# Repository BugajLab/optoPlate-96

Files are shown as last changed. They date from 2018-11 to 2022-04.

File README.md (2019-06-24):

# optoPlate-96
This repository contains all design files, documentation, and code for you to build and use your own optoPlate-96.
The optoPlates are a series of open-source devices for high-throughput, multi-color optogenetic experiments in microwell plates. Each well of a 96-well plate can be illuminated with up to 3 wavelengths of light, with independent control of illumination timing and intensity for each wavelength. We designed the optoPlates for robust operation in standard cell culture incubators, and for straightforward assembly and use. The optoPlate-96 can be assembled in a few hours with no specialized equipment, at a total cost of ~$600. These devices have enabled us to perform complex, quantitative, and reproducible optogenetic experiments over timescales ranging from minutes to weeks. We hope you will find them equally enabling.

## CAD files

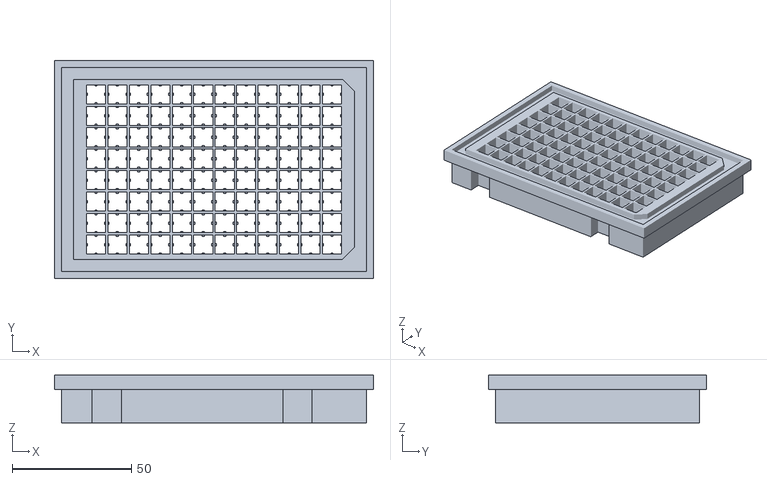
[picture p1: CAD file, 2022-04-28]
1. Assembly_Files/2. 3Dprinting/adapter_96w_384w_TALL.stl
133.8 x 91.5 x 20.0

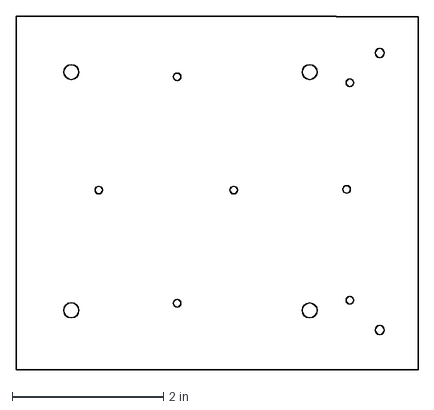
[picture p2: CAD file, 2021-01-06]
1. Assembly_Files/4. WaterjetCutting/aluminumPlateSmall.dxf
5.31 x 4.67 in

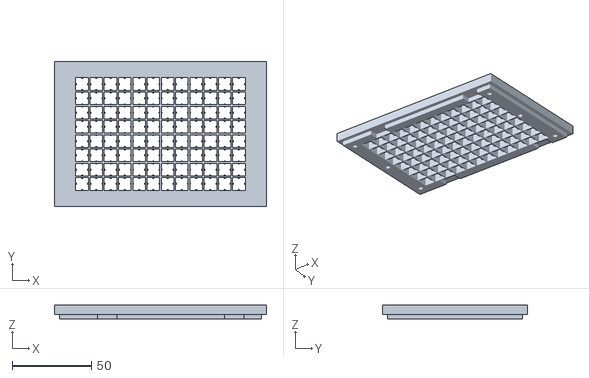
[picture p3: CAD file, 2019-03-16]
1. Assembly_Files/2. 3Dprinting/adapter_96w_384w_SHORT.stl
133.8 x 91.5 x 9.00

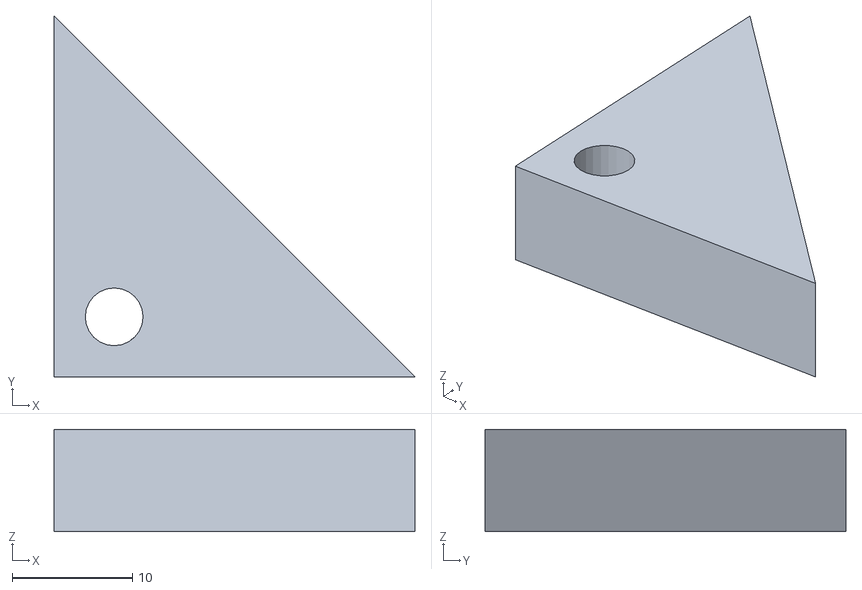
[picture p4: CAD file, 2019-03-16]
1. Assembly_Files/2. 3Dprinting/heatsinkPedestal_v2.stl
30.0 x 30.0 x 8.50

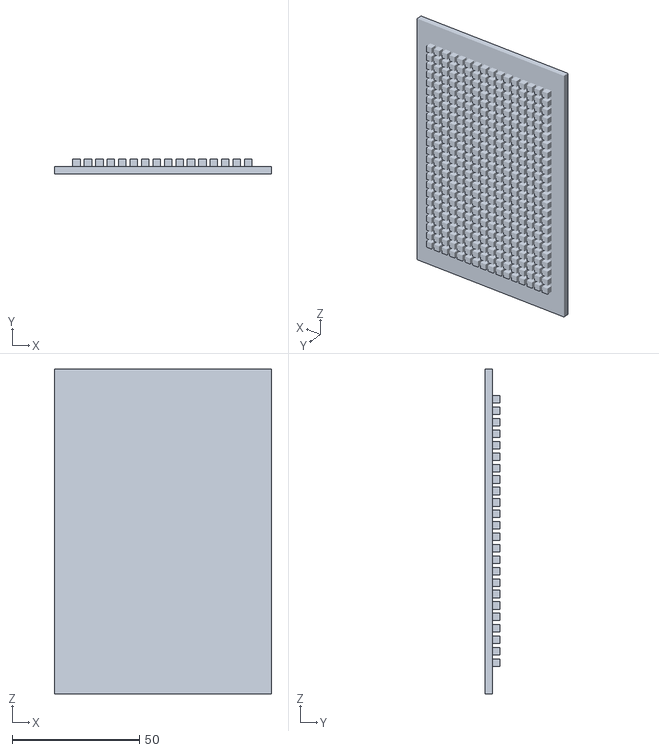
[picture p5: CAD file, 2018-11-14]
1. Assembly_Files/2. 3Dprinting/lid_384w.stl
85.5 x 6.00 x 127.8

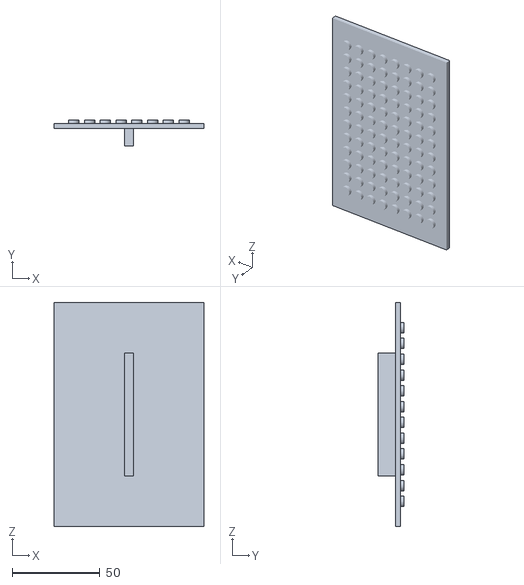
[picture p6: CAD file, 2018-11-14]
1. Assembly_Files/2. 3Dprinting/lid_96w.stl
85.5 x 15.0 x 127.8

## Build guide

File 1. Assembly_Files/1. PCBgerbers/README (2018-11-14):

This folder provides all design files necessary for manufacture of the optoplate illuminator printed circuit board (PCB). 
Included are 11 Gerber files and 1 drill file.
The .zip file contains all necessary Gerber and drill files and can be submitted directly to the PCB manufacturer.

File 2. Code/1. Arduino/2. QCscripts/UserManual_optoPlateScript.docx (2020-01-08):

Lukasz Bugaj

Bugaj Lab

November 18, 2018

User Manual

optoPlate-96_1colorPulse.ino

optoPlate-96_2colorPulse.ino

optoPlate-96_3colorPulse.ino

These scripts control the optoPlate-96, allowing complete control of illumination parameters (timing and intensity) for up to 3 colors for each of 96 positions.

NOTE: Although this manual refers to illumination wavelengths for the 3-color optoPlate configuration (for blue, red, and far-red illumination), the manual applies to all configurations. 1- and 2-color configurations will simply have fewer light intensity variables to specify.

The optoPlate-96_XcolorPulse.ino scripts provide a simple yet powerful framework for dynamic optogenetic perturbations, as described below. However, the optoPlate-96 may be programmed for arbitrarily complex illuminations through customization of the code.

To run this code, the Adafruit_TLC5947 library must be installed. For help installing custom, visit: https://www.arduino.cc/en/Guide/Libraries. Documentation for the Adafruit_TLC5947 library can be found here (https://learn.adafruit.com/tlc5947-tlc59711-pwm-led-driver-breakout/downloads-and-links).

Phases of experiment

The general illumination program consists of 4 programmable phases that allow pulsing cells between 2 experimental illumination conditions (Figure 1A):

0: phaseDelay: the amount of time to delay the start of illumination. This is primarily useful in timecourse experiments when staggered starts are required.

1: phase1: the first illumination condition (can be thought of as the ON phase)

2: phase2: the second illumination condition (or, the OFF phase)

There is also an OFF phase (phaseOFF), in which all LEDs are turned off.

For each phase 0-2, the user can define the duration and intensity of each illumination color. The duration of each phase is specified for each individual LED (phaseTimes). Intensities within each phase can be specified globally for all LEDs or locally for each individual LED.

During an experiment, the LEDs will display the defined illumination conditions sequentially (phaseDelay -> phase1 -> phase2) for the durations specified. Once the end of phase2 has been reached, illumination cycles back to phase1, and the program oscillates between phase1 and phase2 indefinitely following the defined phase timings. If only illumination in phase1 is desired (only ON illumination), then the duration of phase1 should be set arbitrarily large (longer than the desired experiment). Similarly, if the experiment requires that illumination progresses through phase1 and phase2 exactly once, then the duration of phase2 should be defined arbitrarily large.

Pulsing

Within each phase, illumination can be either pulsed or constant (Figure 1B). Pulsed illumination is recommended to minimize both cellular phototoxicity and heat generation from the optoPlate illuminator (heat scales with the amount of power used – or, the total light output). Pulsing parameters—pulse width (pulse) and pulse period (interval)—can be defined for each individual LED. Note that these parameters will dictate pulsing across all phases of illumination (phaseDelay, phase1, phase2) (Figure 1B).

Within phase1, there is also the option to specify illumination during the OFF pulse (the duration between pulsing of phase1-defined illumination settings, Figure 1C). This is mostly useful for three-color optogenetic control of red- and blue-sensitive optogenetic tools (eg, PhyB and iLid), where blue light (ON pulse) must be followed by far-red light (OFF pulse) to prevent blue-light cross-activation of PhyB. The intensity and duration of this OFF pulse are customizable, though the OFF pulse duration should not exceed the amount of time between ON pulses (eg, if the interval is 5s and the ON pulse is 2s, OFF pulse illumination should be < 3s).

Transitions between phases

When the program transitions to phase1 or phase2 and pulsing is used, the ON->OFF or OFF->ON transitions of optogenetic tools can be slower than desired. To speed the activation or inactivation of optogenetic probes, the user can define a length of time (on_millis, off_millis) during which the new illumination setting will constant (not pulsed)(Figure 1D). This results in more step-like (in)activation of the optogenetic probe, and the new state can be further maintained through pulsed illumination. This timing parameter can be defined individually for each position or globally for all wells (on_millisGlobal, off_millisGlobal).

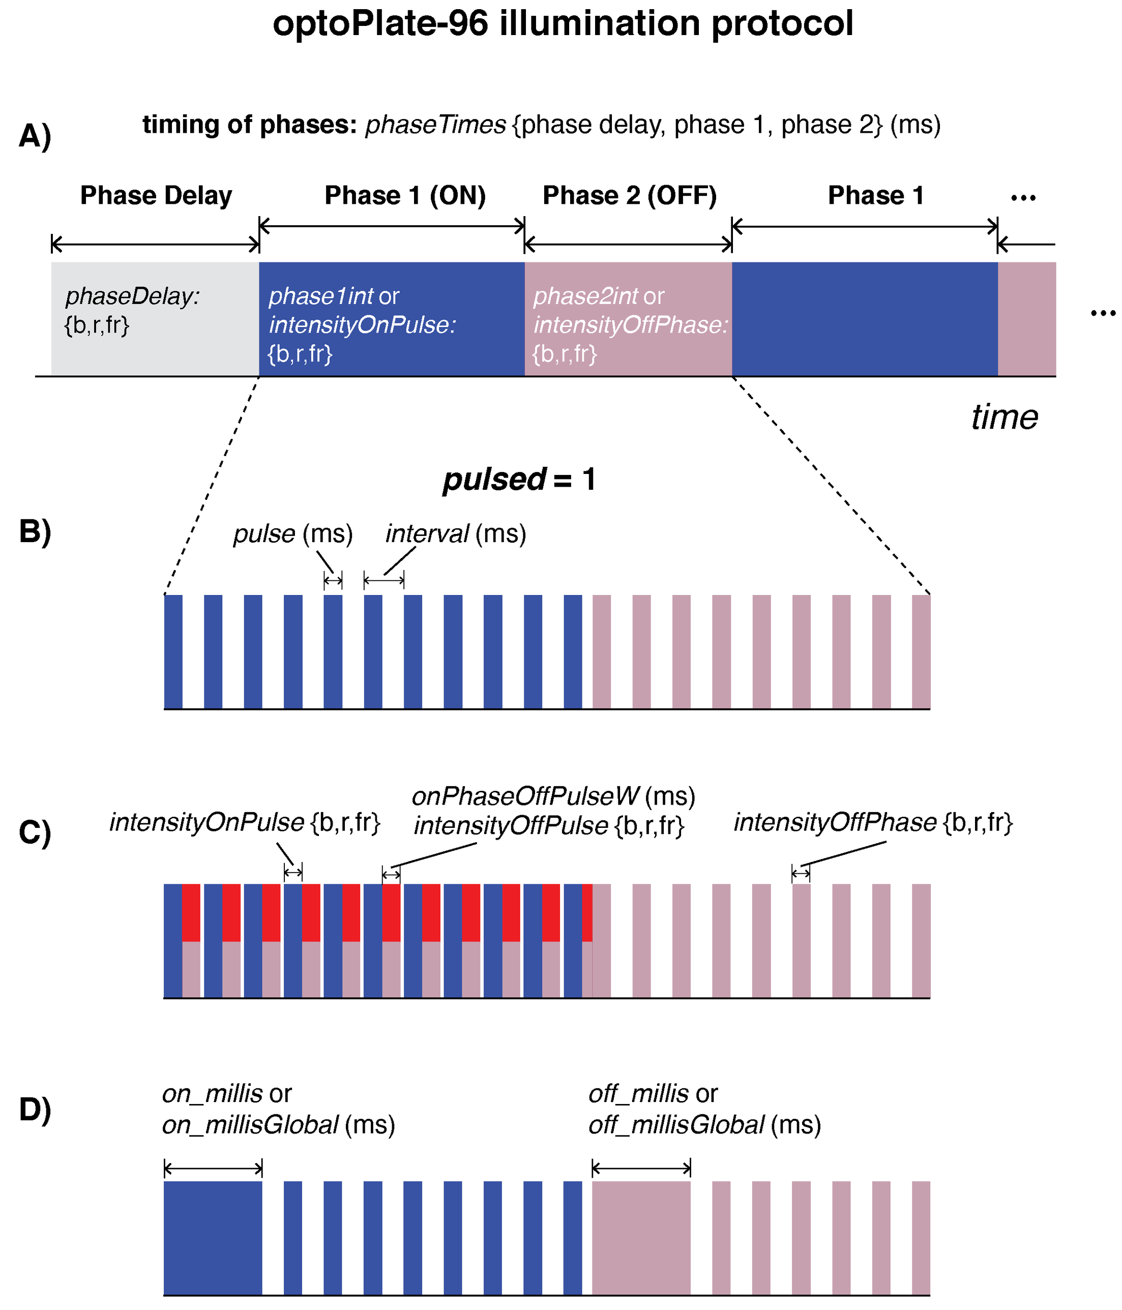
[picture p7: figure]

Figure 1 Visualization of optoPlate-96 illumination protocols and variable definitions. Color of bars indicates colors that would be used in a typical 3-color optogenetic experiment. In the examples provided, phaseDelay could have no illumination, or could illuminate with inactivating far-red light. phase1 would illuminate activating blue or red light, and compensatory far-red light to prevent blue light cross-activation of PhyB. phase2 would illuminate with inactivating far-red light.

A) Schematic of experimental phases. B) If pulsed = 1, pulse and interval define the pulsing parameters. C) Intensity variables are depicted. For 3-color experiments, onPhaseOffPulseW and onPhaseOffPulse allow definition of intensity and timing illumination between activating pulses. D) on_millis and off_millis define the timing of constant illumination at the start of a new illumination phase. This enables more step-like (vs gradual) transitions between phases.

The script is divided into 3 sections:

SECTION 1: This section defines all the variables for each experiment. Variables that need not be changed are labeled *DO NOT CHANGE*. Below are notes on important variables to define:

Time variables: time variables are defined globally, and pointers are used throughout the script to reference these variables. For example, &m30 and &s30 are used to point to the variables that specify 30 minutes and 30 seconds, respectively. Additional time values can be added as new variables in the first section. When adding new variables, make sure to copy the syntax of the other variables. Also, when adding a new time variable, add a corresponding variable in Section 2 in the “test mode” loop. This will ensure that this time variable is properly scaled in test mode.

LEDmode: this defines which of the 96 positions on the LED illuminator are operational. Values are laid out in 96-well format and correspond to LED layout.

Note: arrays of values are most easily defined in a spreadsheet (eg Excel) and then copied and pasted into the Arduino environment

phaseTimes: defines the duration of each phase for each of the 96 LED positions. This variable in particular is most easily defined in a spreadsheet and copied over.

useVarOnPulseIntensity

useVarOffPulseIntensity

useVarOffPhaseIntensity: determine whether LED intensities will be globally defined (0) or variably specified (1) for each individual LED.

intensityOnPulse

intensityOffPulse

intensityOffPhase: define intensities for each color for individual LEDs. First define 96 blue values, then 96 red values, then 96 far-red values.

pulsed: define whether LED illumination will be pulsed (1) or constant (0)

interval, pulse, onPhaseOffPulseW: define pulse periods and pulse widths. Here (and only here), use integer values of milliseconds (do not use pointers to the time variables defined earlier)

varOn, varOff: if constant illumination will be used after transitioning between phases, define whether this will be globally specified (0) or individually for each LED (1).

test: define whether to run the protocol in test mode (test = 1). Test mode allows you to rapidly verify that you have correctly programmed your experiment by speeding up the program by a defined factor. It is strongly recommended to run every protocol in test mode before each experiment to verify correct programming. In test mode, LED illumination is constant (pulsed = 0).

factor: define by what factor to speed up the experiment in test mode.

fanSpeed: define the speed of the fan on the heatsink. The faster the fan, the less sample heating occurs during the experiment. Fan speed can be set from ~100-255. Lower speeds (<100) may result in no fan spinning. Generally, max speed (255) is recommended.

SECTION 2: This is the setup function. This sets the initial settings for the optoPlate run.

SECTION 3: This is the loop function. This code executes the optoPlate experiment as defined by the variables in Section 1.

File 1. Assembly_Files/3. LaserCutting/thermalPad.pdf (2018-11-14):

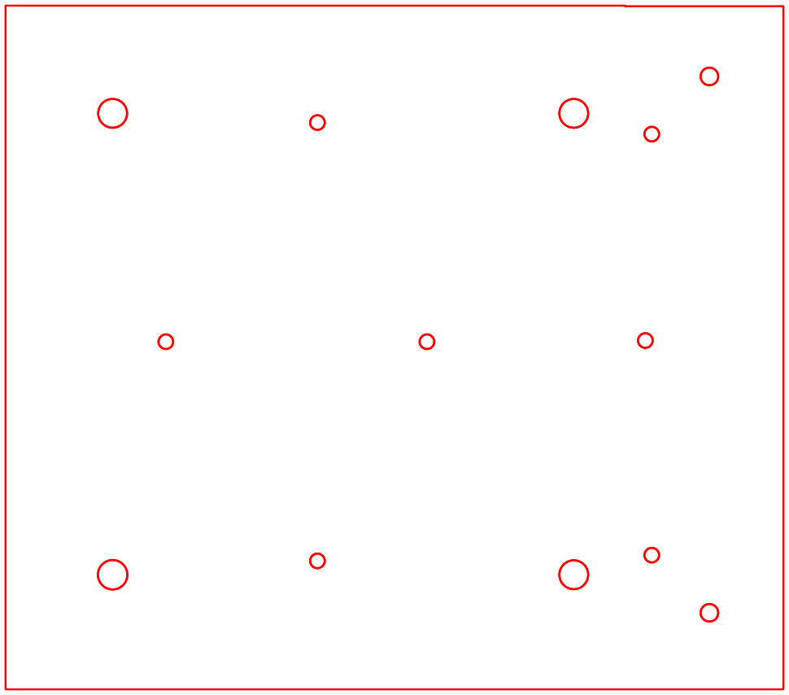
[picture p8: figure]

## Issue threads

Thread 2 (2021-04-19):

Problem with test = 1

mathiaslec, 2021-04-19:
Hi,
Thank you for this amazing tool, we are building an optoplate here!
It looks like there was a error in the code when running it in test mode, some LEDs would not light up.
I fixed it, would you accept a pull request ?
Thank you.

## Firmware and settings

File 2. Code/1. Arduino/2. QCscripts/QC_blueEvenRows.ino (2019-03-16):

#include "Adafruit_TLC5947.h"
#include "Arduino.h"
#include <avr/pgmspace.h>

// How many boards do you have chained?
const uint8_t NUM_TLC5974 = 12;

const uint8_t data  = 4;
const uint8_t clock = 5;
const uint8_t latch = 6;
const uint8_t oe  = 7;  // set to -1 to not use the enable pin (its optional)

//defines numbers of channels total for all colors (288 channels for 3 col 96 well plate)
const int chanNum = 24*NUM_TLC5974;
 
//defines state of pins (0 = OFF)
uint8_t ledState[chanNum/3] = {0};

//Cycle number (for fine pulsing)
uint16_t cycNum[chanNum/3] = {0};
                           
Adafruit_TLC5947 tlc = Adafruit_TLC5947(NUM_TLC5974, clock, data, latch);

// Define whether individual positions will be OFF (0), in timecourse mode (1), or in constant light setting mode (2) (in flash memory, read only)  Rows: A-H. Columns: 1-12                                  
uint8_t const LEDmode[] PROGMEM ={ 
/*
0,  1,  0,  1,  0,  1,  0,  1,  0,  1,  0,  1,
0,  1,  0,  1,  0,  1,  0,  1,  0,  1,  0,  1,
0,  1,  0,  1,  0,  1,  0,  1,  0,  1,  0,  1,
0,  1,  0,  1,  0,  1,  0,  1,  0,  1,  0,  1,
0,  1,  0,  1,  0,  1,  0,  1,  0,  1,  0,  1,
0,  1,  0,  1,  0,  1,  0,  1,  0,  1,  0,  1,
0,  1,  0,  1,  0,  1,  0,  1,  0,  1,  0,  1,
0,  1,  0,  1,  0,  1,  0,  1,  0,  1,  0,  1,
*/

0, 0, 0, 0, 0, 0, 0, 0, 0, 0, 0, 0, 
1, 1, 1, 1, 1, 1, 1, 1, 1, 1, 1, 1,
0, 0, 0, 0, 0, 0, 0, 0, 0, 0, 0, 0, 
1, 1, 1, 1, 1, 1, 1, 1, 1, 1, 1, 1,
0, 0, 0, 0, 0, 0, 0, 0, 0, 0, 0, 0, 
1, 1, 1, 1, 1, 1, 1, 1, 1, 1, 1, 1,
0, 0, 0, 0, 0, 0, 0, 0, 0, 0, 0, 0,
1, 1, 1, 1, 1, 1, 1, 1, 1, 1, 1, 1
};       

                          
const uint8_t OFF = 0;
const uint8_t TIMECOURSE = 1;
const uint8_t CONST_INTENSITY = 2;
const uint8_t OFF_TIMECOURSE = 3;

                                  
//Pulse intervals (flash memory, read only)  Rows: A-H. Columns: 1-12
const uint32_t interval[] PROGMEM = {
2000,	2000,	2000,	2000,	2000,	2000,	2000,	2000,	2000,	2000,	2000,	2000,
2000,	2000,	2000,	2000,	2000,	2000,	2000,	2000,	2000,	2000,	2000,	2000,
2000,	2000,	2000,	2000,	2000,	2000,	2000,	2000,	2000,	2000,	2000,	2000,
2000,	2000,	2000,	2000,	2000,	2000,	2000,	2000,	2000,	2000,	2000,	2000,
2000,	2000,	2000,	2000,	2000,	2000,	2000,	2000,	2000,	2000,	2000,	2000,
2000,	2000,	2000,	2000,	2000,	2000,	2000,	2000,	2000,	2000,	2000,	2000,
2000,	2000,	2000,	2000,	2000,	2000,	2000,	2000,	2000,	2000,	2000,	2000,
2000,	2000,	2000,	2000,	2000,	2000,	2000,	2000,	2000,	2000,	2000,	2000,


};

//Pulse widths (flash memory, read only). Rows: A-H. Columns: 1-12
uint32_t const pulse[] PROGMEM = { 
500,	500,	500,	500,	500,	500,	500,	500,	500,	500,	500,	500,
500,	500,	500,	500,	500,	500,	500,	500,	500,	500,	500,	500,
500,	500,	500,	500,	500,	500,	500,	500,	500,	500,	500,	500,
500,	500,	500,	500,	500,	500,	500,	500,	500,	500,	500,	500,
500,	500,	500,	500,	500,	500,	500,	500,	500,	500,	500,	500,
500,	500,	500,	500,	500,	500,	500,	500,	500,	500,	500,	500,
500,	500,	500,	500,	500,	500,	500,	500,	500,	500,	500,	500,
500,	500,	500,	500,	500,	500,	500,	500,	500,	500,	500,	500,
};
                                  
//LED intensity, for constant intensity setting (flash memory, read only). Rows: A-H. Columns: 1-12
uint16_t const intensity[] PROGMEM = { 
 //BLUE INTENSITIES
100,  100,  100,  100,  100,  100,  100,  100,  100,  100,  100,  100,
100,  100,  100,  100,  100,  100,  100,  100,  100,  100,  100,  100,
100,  100,  100,  100,  100,  100,  100,  100,  100,  100,  100,  100,
100,  100,  100,  100,  100,  100,  100,  100,  100,  100,  100,  100,
100,  100,  100,  100,  100,  100,  100,  100,  100,  100,  100,  100,
100,  100,  100,  100,  100,  100,  100,  100,  100,  100,  100,  100,
100,  100,  100,  100,  100,  100,  100,  100,  100,  100,  100,  100,
100,  100,  100,  100,  100,  100,  100,  100,  100,  100,  100,  100,
 
 //RED INTENTSITIES
100,  100,  100,  100,  100,  100,  100,  100,  100,  100,  100,  100,
100,  100,  100,  100,  100,  100,  100,  100,  100,  100,  100,  100,
100,  100,  100,  100,  100,  100,  100,  100,  100,  100,  100,  100,
100,  100,  100,  100,  100,  100,  100,  100,  100,  100,  100,  100,
100,  100,  100,  100,  100,  100,  100,  100,  100,  100,  100,  100,
100,  100,  100,  100,  100,  100,  100,  100,  100,  100,  100,  100,
100,  100,  100,  100,  100,  100,  100,  100,  100,  100,  100,  100,
100,  100,  100,  100,  100,  100,  100,  100,  100,  100,  100,  100,

//FAR RED INTENSITIES
1000,  1000, 1000, 1000, 1000, 1000, 1000, 1000, 1000, 1000, 1000, 1000,
1000, 1000, 1000, 1000, 1000, 1000, 1000, 1000, 1000, 1000, 1000, 1000,
1000, 1000, 1000, 1000, 1000, 1000, 1000, 1000, 1000, 1000, 1000, 1000,
1000, 1000, 1000, 1000, 1000, 1000, 1000, 1000, 1000, 1000, 1000, 1000,
1000, 1000, 1000, 1000, 1000, 1000, 1000, 1000, 1000, 1000, 1000, 1000,
1000, 1000, 1000, 1000, 1000, 1000, 1000, 1000, 1000, 1000, 1000, 1000,
1000, 1000, 1000, 1000, 1000, 1000, 1000, 1000, 1000, 1000, 1000, 1000,
1000, 1000, 1000, 1000, 1000, 1000, 1000, 1000, 1000, 1000, 1000, 1000,
};
                           
//number of phases in timecourse (including initial delay phase
const uint8_t totPhaseNum = 3;

//Set intensities for various phases.
uint16_t phaseOFF[3] = {0,0,0};
uint16_t phaseDELAY[3] = {0,0,4095};
uint16_t phase1int[3] = {100,0, 0};
uint16_t phase2int[3] = {0,0,4095};

//array of phases
uint16_t *phases[totPhaseNum+1] = {phaseOFF, phaseDELAY, phase1int, phase2int};

//define the current phase (0-3), with 0 being OFF
uint8_t currPhase[chanNum/3] = {0};

//Time variables for pulse lengths
uint32_t s0 = 0;
uint32_t s1 = 1000UL*1UL;
uint32_t s5 = 1000UL*5UL;
uint32_t s10 = 1000UL*10UL;
uint32_t s6 = 1000UL*6UL;
uint32_t s12 = 1000UL*12UL;
uint32_t s18 = 1000UL*18UL;
uint32_t s20 = 1000UL*20UL;
uint32_t s24 = 1000UL*24UL;
uint32_t s30 = 1000UL*30UL;
uint32_t s36 = 1000UL*36UL;
uint32_t s42 = 1000UL*42UL;
uint32_t s45 = 1000UL*45UL;
uint32_t s48 = 1000UL*48UL;
uint32_t s60 = 1000UL*60UL;
uint32_t s120 = 1000UL*120UL;

uint32_t  m3 = 60UL*1000UL*3UL;
uint32_t  m4 = 60UL*1000UL*4UL;
uint32_t  m5 =  60UL*1000UL*5UL;
uint32_t  m8 =  60UL*1000UL*8UL;
uint32_t  m9 =  60UL*1000UL*9UL;
uint32_t  m9_15 =  60UL*1000UL*9.25;
uint32_t  m9_30 =  60UL*1000UL*9.5;
uint32_t  m9_40 =  60UL*1000UL*9.66;
uint32_t  m9_50 =  60UL*1000UL*9.83;
uint32_t  m9_55 =  60UL*1000UL*9.916;
uint32_t  m10 = 60UL*1000UL*10UL;
uint32_t  m15 = 60UL*1000UL*15UL;
uint32_t  m20 = 60UL*1000UL*20UL;
uint32_t  m25 = 60UL*1000UL*25UL;
uint32_t  m30 = 60UL*1000UL*30UL;
uint32_t  m35 = 60UL*1000UL*35UL;
uint32_t  m40 = 60UL*1000UL*40UL;
uint32_t  m45 = 60UL*1000UL*45UL;
uint32_t  m50 = 60UL*1000UL*50UL;
uint32_t  m55 = 60UL*1000UL*55UL;
uint32_t  m60 = 60UL*1000UL*60UL;
uint32_t  m65 = 60UL*1000UL*65UL;
uint32_t  m70 = 60UL*1000UL*70UL;
uint32_t  m75 = 60UL*1000UL*75UL;
uint32_t  m80 = 60UL*1000UL*80UL;
uint32_t  m85 = 60UL*1000UL*85UL;
uint32_t  m88 = 60UL*1000UL*88UL;
uint32_t  m89 = 60UL*1000UL*89UL;
uint32_t  m89_30 = 60UL*1000UL*89.5;
uint32_t m90 = 60UL*1000UL*90UL;
uint32_t m95 = 60UL*1000UL*95UL;
uint32_t m100 = 60UL*1000UL*100UL;
uint32_t m110 = 60UL*1000UL*110UL;
uint32_t m120 = 60UL*1000UL*120UL;
uint32_t m125 = 60UL*1000UL*125UL;
uint32_t m135 = 60UL*1000UL*135UL;

uint32_t h2  = 1000UL*60UL*60UL*2UL;
uint32_t h3  = 1000UL*60UL*60UL*3UL;
uint32_t h4  = 1000UL*60UL*60UL*4UL;
uint32_t h6  = 1000UL*60UL*60UL*6UL;
uint32_t h7  = 1000UL*60UL*60UL*7UL;
uint32_t h7_5  = 1000UL*60UL*60UL*7.5;
uint32_t h8  = 1000UL*60UL*60UL*8UL;
uint32_t h12 = 1000UL*60UL*60UL*12UL;
uint32_t h16 = 1000UL*60UL*60UL*16UL;
uint32_t h18 = 1000UL*60UL*60UL*18UL;
uint32_t h19 = 1000UL*60UL*60UL*19UL;
uint32_t h20 = 1000UL*60UL*60UL*20UL;
uint32_t h22 = 1000UL*60UL*60UL*22UL;
uint32_t h24 = 1000UL*60UL*60UL*24UL;
uint32_t h26 = 1000UL*60UL*60UL*26UL;
uint32_t h30 = 1000UL*60UL*60UL*30UL;
uint32_t h36 = 1000UL*60UL*60UL*36UL;
uint32_t h42 = 1000UL*60UL*60UL*42UL;
uint32_t h48 = 1000UL*60UL*60UL*48UL;

//defines timecourse for each channel as array of pointers
const uint32_t * const phaseTimes[chanNum/3][totPhaseNum] PROGMEM = {
{&s0,&h48,&m10},  {&s0,&h48,&m10},  {&s0,&h48,&m10},  {&s0,&h48,&m10},  {&s0,&h48,&m10},  {&s0,&h48,&m10},  {&s0,&h48,&m10},  {&s0,&h48,&m10},  {&s0,&h48,&m10},  {&s0,&h48,&m10},  {&s0,&h48,&m10},  {&s0,&h48,&m10},
{&s0,&h48,&m10},  {&s0,&h48,&m10},  {&s0,&h48,&m10},  {&s0,&h48,&m10},  {&s0,&h48,&m10},  {&s0,&h48,&m10},  {&s0,&h48,&m10},  {&s0,&h48,&m10},  {&s0,&h48,&m10},  {&s0,&h48,&m10},  {&s0,&h48,&m10},  {&s0,&h48,&m10},
{&s0,&h48,&m10},  {&s0,&h48,&m10},  {&s0,&h48,&m10},  {&s0,&h48,&m10},  {&s0,&h48,&m10},  {&s0,&h48,&m10},  {&s0,&h48,&m10},  {&s0,&h48,&m10},  {&s0,&h48,&m10},  {&s0,&h48,&m10},  {&s0,&h48,&m10},  {&s0,&h48,&m10},
{&s0,&h48,&m10},  {&s0,&h48,&m10},  {&s0,&h48,&m10},  {&s0,&h48,&m10},  {&s0,&h48,&m10},  {&s0,&h48,&m10},  {&s0,&h48,&m10},  {&s0,&h48,&m10},  {&s0,&h48,&m10},  {&s0,&h48,&m10},  {&s0,&h48,&m10},  {&s0,&h48,&m10},
{&s0,&h48,&m10},  {&s0,&h48,&m10},  {&s0,&h48,&m10},  {&s0,&h48,&m10},  {&s0,&h48,&m10},  {&s0,&h48,&m10},  {&s0,&h48,&m10},  {&s0,&h48,&m10},  {&s0,&h48,&m10},  {&s0,&h48,&m10},  {&s0,&h48,&m10},  {&s0,&h48,&m10},
{&s0,&h48,&m10},  {&s0,&h48,&m10},  {&s0,&h48,&m10},  {&s0,&h48,&m10},  {&s0,&h48,&m10},  {&s0,&h48,&m10},  {&s0,&h48,&m10},  {&s0,&h48,&m10},  {&s0,&h48,&m10},  {&s0,&h48,&m10},  {&s0,&h48,&m10},  {&s0,&h48,&m10},
{&s0,&h48,&m10},  {&s0,&h48,&m10},  {&s0,&h48,&m10},  {&s0,&h48,&m10},  {&s0,&h48,&m10},  {&s0,&h48,&m10},  {&s0,&h48,&m10},  {&s0,&h48,&m10},  {&s0,&h48,&m10},  {&s0,&h48,&m10},  {&s0,&h48,&m10},  {&s0,&h48,&m10},
{&s0,&h48,&m10},  {&s0,&h48,&m10},  {&s0,&h48,&m10},  {&s0,&h48,&m10},  {&s0,&h48,&m10},  {&s0,&h48,&m10},  {&s0,&h48,&m10},  {&s0,&h48,&m10},  {&s0,&h48,&m10},  {&s0,&h48,&m10},  {&s0,&h48,&m10},  {&s0,&h48,&m10},
};

//Define constant off times for OFF_TIMECOURSE setting
const uint32_t * const off_millis[] PROGMEM ={
&s0,  &s0,  &s0,  &s0,  &s0,  &s0,  &s0,  &s0,  &s0,  &s0,  &s0,  &s0,
&s0,  &s0,  &s0,  &s0,  &s0,  &s0,  &s0,  &s0,  &s0,  &s0,  &s0,  &s0,
&s0,  &s0,  &s0,  &s0,  &s0,  &s0,  &s0,  &s0,  &s0,  &s0,  &s0,  &s0,
&s0,  &s0,  &s0,  &s0,  &s0,  &s0,  &s0,  &s0,  &s0,  &s0,  &s0,  &s0,
&s0,  &s0,  &s0,  &s0,  &s0,  &s0,  &s0,  &s0,  &s0,  &s0,  &s0,  &s0,
&s0,  &s0,  &s0,  &s0,  &s0,  &s0,  &s0,  &s0,  &s0,  &s0,  &s0,  &s0,
&s0,  &s0,  &s0,  &s0,  &s0,  &s0,  &s0,  &s0,  &s0,  &s0,  &s0,  &s0,
&s0,  &s0,  &s0,  &s0,  &s0,  &s0,  &s0,  &s0,  &s0,  &s0,  &s0,  &s0,
}; //H   
                                  
                                  
//Define constant on times for variable constant Red ON times
const uint32_t * const on_millis[] PROGMEM ={
&s0,	&s0,	&s0,	&s0,	&s0,	&s0,	&s0,	&s0,	&s0,	&s0,	&s0,	&s0,
&s0,	&s0,	&s0,	&s0,	&s0,	&s0,	&s0,	&s0,	&s0,	&s0,	&s0,	&s0,
&s0,  &s0,  &s0,  &s0,  &s0,  &s0,  &s0,  &s0,  &s0,  &s0,  &s0,  &s0,
&s0,  &s0,  &s0,  &s0,  &s0,  &s0,  &s0,  &s0,  &s0,  &s0,  &s0,  &s0,
&s0,  &s0,  &s0,  &s0,  &s0,  &s0,  &s0,  &s0,  &s0,  &s0,  &s0,  &s0,
&s0,  &s0,  &s0,  &s0,  &s0,  &s0,  &s0,  &s0,  &s0,  &s0,  &s0,  &s0,
&s0,  &s0,  &s0,  &s0,  &s0,  &s0,  &s0,  &s0,  &s0,  &s0,  &s0,  &s0,
&s0,  &s0,  &s0,  &s0,  &s0,  &s0,  &s0,  &s0,  &s0,  &s0,  &s0,  &s0,
};  

// define time that IR or Red will be constantly on after ON->OFF transition and OFF->ON transition
uint32_t *IRoffSwitch =  &m5;
uint32_t *REDonSwitch =  &s60;

//define pointers to be used in script for pointing to either a constant switch time or to the variable switch times (on_millis, offmillis)
uint32_t *offTime;
uint32_t *onTime;




//define flag to determine whther a channel has just switched to an OFF(1) or OFF (2) phase. 
uint8_t switchTo[chanNum/3] = { 
  0,0,0,0,0,0,0,0,0,0,0,0,
  0,0,0,0,0,0,0,0,0,0,0,0,
  0,0,0,0,0,0,0,0,0,0,0,0,
  0,0,0,0,0,0,0,0,0,0,0,0,
  0,0,0,0,0,0,0,0,0,0,0,0,
  0,0,0,0,0,0,0,0,0,0,0,0,
  0,0,0,0,0,0,0,0,0,0,0,0,
  0,0,0,0,0,0,0,0,0,0,0,0};
                                  
//define flag to determine if channel just switched to ON phase                                

//define if using phase intensities or variable intensities. 0 to use phase intensities, 1 to use variable.
uint8_t useVarIntensity = 0;

//define if pulsed or constant. 1 for pulsed, 0 for constant
uint8_t pulsed = 0;

//define if in test mode. If in test mode, define "factor" for how much to divide phase times by
uint8_t test = 0;

uint32_t factor = 60UL; //times change from hours to seconds

//keep track of when switched to the current phase
uint32_t lastPhaseSwitch[chanNum/3] = {0};

//use variable times for ON or OFF constant illumination when to red or IR (1 yes, 0 no)?
uint8_t varON = 0;
uint8_t varOFF = 0;

void setup() {
  Serial.begin(9600);
  tlc.begin();
  
  //set initial LED states to 0
  for (int i = 0; i < chanNum/3; i++){
    setAll(i,phaseOFF);
    cycNum[i] = 0;}
    tlc.write();
  
  if (oe >= 0) {
    pinMode(oe, OUTPUT);
    digitalWrite(oe, HIGH);
    }
    
  //if in test mode, divide phase times by defined factor amount to visualize entire timecourse
  if (test){
     s1 = (uint32_t)s1/factor;
     s5 = (uint32_t)s5/factor;
     s10 = (uint32_t)s10/factor;
    s30 = (uint32_t)s30/factor;
    s60 = (uint32_t)s60/factor;
    s120 = (uint32_t)s120/factor;
  
     m3 =  (uint32_t)m3/factor; 
     m4 =  (uint32_t)m4/factor;
     m5 =  (uint32_t)m5/factor;
     m10 = (uint32_t)m10/factor;
     m15 = (uint32_t)m15/factor;
     m20 = (uint32_t)m20/factor;
     m25 = (uint32_t)m25/factor;
     m30 = (uint32_t)m30/factor;
     m35 = (uint32_t)m35/factor;
     m40 = (uint32_t)m40/factor;
     m45 = (uint32_t)m45/factor;
     m50 = (uint32_t)m50/factor;
     m55 = (uint32_t)m55/factor;
     m60 = (uint32_t)m60/factor;
     m65 = (uint32_t)m65/factor;
     m70 = (uint32_t)m70/factor;
     m75 = (uint32_t)m75/factor;
     m80 = (uint32_t)m80/factor;
     m85 = (uint32_t)m85/factor;
     m90 = (uint32_t)m90/factor;
     m95 = (uint32_t)m95/factor;
     m100 = (uint32_t)m100/factor;
     m110 = (uint32_t)m110/factor;
     m120 =(uint32_t)m120/factor;
     m125 =(uint32_t)m125/factor;
     m135 =(uint32_t)m135/factor;
    
    h2 =  (uint32_t)h2/factor;
     h3 =  (uint32_t)h3/factor;
     h4 =  (uint32_t)h4/factor;
     h6 =  (uint32_t)h6/factor;
     h7 = (uint32_t)h7/factor;
     h7_5 = (uint32_t)h7_5/factor;
     h8 =  (uint32_t)h8/factor;
     h12 = (uint32_t)h12/factor;
     h16 = (uint32_t)h16/factor;
     h18 = (uint32_t)h18/factor;
     h19 = (uint32_t)h19/factor;
     h20 = (uint32_t)h20/factor;
     h22 = (uint32_t)h22/factor;
     h24 = (uint32_t)h24/factor;
     h26 = (uint32_t)h26/factor;
     h30 = (uint32_t)h30/factor;
     h36 = (uint32_t)h36/factor;
     h42 = (uint32_t)h42/factor;
     h48 = (uint32_t)h48/factor;  
  }

//set initial LED states to first pulse intensity
  for (int i = 0; i < chanNum/3; i++){
    uint8_t mode = pgm_read_word_near(LEDmode+i);
    if(mode == TIMECOURSE || mode == OFF_TIMECOURSE){
      setAll(i,phaseDELAY);
      currPhase[i] = 1;
      ledState[i] = 1;
    }
  }
  tlc.write();
}
  
  
void loop(){
  
 uint8_t changed = 0;
 unsigned long currMillis = millis();
 uint8_t phaseChanged = 0;
 
  //Identify correct illlumination phase, update LED settings
   for (uint16_t i = 0; i<chanNum/3; i++){
     uint8_t mode = pgm_read_word_near(LEDmode+i);
     
     if(mode != OFF){
       if(mode == TIMECOURSE){       //Loops to compare current time against timecourse timing, and also to hold light settings at last timepoint 
         uint32_t *phaseT = (uint32_t*)pgm_read_word_near(&phaseTimes[i][currPhase[i]-1]);         
         if (currMillis -lastPhaseSwitch[i] > *phaseT){
           lastPhaseSwitch[i] = lastPhaseSwitch[i] + *phaseT;
           if (currPhase[i] == 2){  //if phase is 2, go to 3
             currPhase[i] = 3;
             switchTo[i] = 1;
             phaseChanged = 1; //Set flag to indicate that channel has just switched from ON to OFF
           } 
           else{
             currPhase[i] = 2; //if phase is 1(delay) or 3, go to 2
             phaseChanged = 1;
             switchTo[i] = 2;
           } //set flag to indicate that channel has just been switched ON
         }
       }
       
       //Specially for OFF_timecourse
       if( mode == OFF_TIMECOURSE){       //Loops to compare current time against timecourse timing, and also to hold light settings at last timepoint 
         uint32_t *phaseT = (uint32_t*)pgm_read_word_near(&phaseTimes[i][currPhase[i]-1]);         
         if (currMillis -lastPhaseSwitch[i] > *phaseT && switchTo[i] == 0){
           if (currPhase[i] == 1){
             currPhase[i] = 2;
             lastPhaseSwitch[i] = lastPhaseSwitch[i] + *phaseT;
             phaseChanged = 1;
           }
           else if (currPhase[i] == 2){  //if phase is 2, go to 3
             currPhase[i] = 3;
             lastPhaseSwitch[i] = lastPhaseSwitch[i] + *phaseT;
             switchTo[i] = 1; //Set flag to indicate that channel has just switched from ON to OFF
             phaseChanged = 1;
           } 
       }
       }
       
      //Setting new LED settings in constant (non-pulsed) light setting
      if (!pulsed){
        if(mode == TIMECOURSE || mode == OFF_TIMECOURSE){
          if (phaseChanged){
             if (currPhase[i] == 2 && useVarIntensity){
               uint16_t blueInt = pgm_read_word_near(intensity+i);
               uint16_t redInt = pgm_read_word_near(intensity+i+96);
               uint16_t fredInt = pgm_read_word_near(intensity+i+192);
               uint16_t intensities[3] = {blueInt, redInt, fredInt};
               setAll(i, intensities);
               changed = 1;
             }
             else{
               setAll(i,phases[currPhase[i]]);
               changed = 1;
             }
           }  
        } 
        else if (mode == CONST_INTENSITY){
         
            uint16_t blueInt = pgm_read_word_near(intensity+i);
            uint16_t redInt = pgm_read_word_near(intensity+i+96);
            uint16_t fredInt = pgm_read_word_near(intensity+i+192);
            uint16_t intensities[3] = {blueInt, redInt, fredInt};              
            setAll(i, intensities);
            changed = 1;
         }
      }      
      
     //Setting new LED settings in pulsed light setting
      if (pulsed){
         uint32_t memInterval = pgm_read_dword(interval+i);
         uint32_t memPulse = pgm_read_dword(pulse+i);
         uint32_t prevMillis = (uint32_t)cycNum[i]*memInterval;
         
         if (currMillis-prevMillis > memInterval && ledState[i] == 0) { //if interval time expired, turn LED ON
              ledState[i] = 1;          //set LED flag to ON
              cycNum[i] = cycNum[i]+1;  //increment cycle
              if (mode == TIMECOURSE || mode == OFF_TIMECOURSE){ 
                if (currPhase[i] == 2 && useVarIntensity){
                  uint16_t blueInt = pgm_read_word_near(intensity+i);
                  uint16_t redInt = pgm_read_word_near(intensity+i+96);
                  uint16_t fredInt = pgm_read_word_near(intensity+i+192);
                  uint16_t intensities[3] = {blueInt, redInt, fredInt};
                  setAll(i, intensities);
                  changed = 1;
                }
                else{
                  setAll(i, phases[currPhase[i]]); //set all LED intensities to the current phase
                  changed = 1;        //set the "LED changed" flag to write to LEDs
                }
              }
         }
         else {
              if (currMillis-prevMillis> memPulse && ledState[i] == 1){  // if pulse time expired, turn LED OFF
                ledState[i] = 0;             //set LED flag to OFF
                changed = 1;                 //set the "LED changed" flag to write to LEDs
                setAll(i,phaseOFF);         //set LED OFF   
              }  
            } 
          }
          
          //Loops to check if LED as just turned from ON to OFF or OFF to ON. If so, keep IR or Red ON constantly, respectively.
         
         //Define constant OFF time based on setup
         if (switchTo[i] == 1){
           if (varOFF){
            offTime =  (uint32_t*)pgm_read_word_near(off_millis+i);}
           else {
            offTime =  IRoffSwitch;}
          }
        
         // Define constant ON time based on setup
         if (switchTo[i] == 2){
           if (varON){
            onTime =  (uint32_t*)pgm_read_word_near(on_millis+i);}
           else {
            onTime =  REDonSwitch;}
         }
     
         if (mode == TIMECOURSE){
           if (switchTo[i] ==1 && (currMillis-lastPhaseSwitch[i]) < *offTime){
            setAll(i,phase2int);
            changed = 1;}
           else if (switchTo[i] == 1 && (currMillis - lastPhaseSwitch[i]) > *offTime){
             switchTo[i] = 0;
             setAll(i,phaseOFF);
             changed = 1;}
           else if (switchTo[i] == 2 && (currMillis - lastPhaseSwitch[i]) < *onTime){
             if (useVarIntensity){
               uint16_t blueInt = pgm_read_word_near(intensity+i);
               uint16_t redInt = pgm_read_word_near(intensity+i+96);
               uint16_t fredInt = pgm_read_word_near(intensity+i+192);
               uint16_t intensities[3] = {blueInt, redInt, fredInt};
               setAll(i, intensities);
               changed = 1;}
             else{
               setAll(i,phase1int);
               changed = 1;}
           }
           else if (switchTo[i] == 2 && (currMillis - lastPhaseSwitch[i]) > *onTime){
             switchTo[i] = 0;
             setAll(i,phaseOFF);
             ledState[i] = 0;
             changed = 1;}
         }
     }
   }
   
//if LED settings were updated, then write new settings to LEDs
  if (changed){
    tlc.write();
    changed = 0;
  }
}



//FUNCTIONS to control LED colors
void setBlue(uint16_t well, uint16_t *bright){
  uint16_t bluePosition = (uint16_t)((int)(well/12) + 8*(well%12));
  tlc.setPWM(bluePosition, *bright);   //Set Blue
}
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

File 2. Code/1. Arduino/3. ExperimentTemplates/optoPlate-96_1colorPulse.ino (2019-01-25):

#include "Adafruit_TLC5947.h"
#include "Arduino.h"
#include <avr/pgmspace.h>

/////////////////////////////////////////////////////////////////////////////////////////////////
//SECTION 1: Variable definitions
//SECTION 1: Variable definitions
//SECTION 1: Variable definitions
///////////////////////////////////////////////////////////////////////////////////////////////// 

//DO NOT CHANGE 
//define number of LED drivers and assign microcontroller
const uint8_t NUM_TLC5974 = 12; 
const uint8_t data  = 4;
const uint8_t clock = 5;
const uint8_t latch = 6;
const uint8_t oe  = 7;  // set to -1 to not use the enable pin (its optional)

//DO NOT CHANGE
const int chanNum = 24*NUM_TLC5974; //number of channels
const uint8_t OFF = 0; //defines state variable for OFF state
uint8_t ledState[chanNum/3] = {0}; //tracks the LED state (ON or OFF)
uint32_t cycNum[chanNum/3] = {0}; //counts number of pulsing cycles
Adafruit_TLC5947 tlc = Adafruit_TLC5947(NUM_TLC5974, clock, data, latch); //creates LED driver object

//Define time variables for script
//Add definitions as needed, following the provided syntax
//Also make sure to add associated definition to "test mode" timing in Section 2
//SECONDS
uint32_t s0 = 0;
uint32_t s1 = 1000UL*1UL;
uint32_t s5 = 1000UL*5UL;
uint32_t s10 = 1000UL*10UL;
uint32_t s6 = 1000UL*6UL;
uint32_t s12 = 1000UL*12UL;
uint32_t s18 = 1000UL*18UL;
uint32_t s20 = 1000UL*20UL;
uint32_t s24 = 1000UL*24UL;
uint32_t s30 = 1000UL*30UL;
uint32_t s36 = 1000UL*36UL;
uint32_t s42 = 1000UL*42UL;
uint32_t s45 = 1000UL*45UL;
uint32_t s48 = 1000UL*48UL;
uint32_t s60 = 1000UL*60UL;
uint32_t s90 = 1000UL*90UL;
uint32_t s120 = 1000UL*120UL;

//MINUTES
uint32_t  m2 = 60UL*1000UL*2UL;
uint32_t  m3 = 60UL*1000UL*3UL;
uint32_t  m4 = 60UL*1000UL*4UL;
uint32_t  m5 =  60UL*1000UL*5UL;
uint32_t  m6 =  60UL*1000UL*6UL;
uint32_t  m8 =  60UL*1000UL*8UL;
uint32_t  m9 =  60UL*1000UL*9UL;
uint32_t  m9_15 =  60UL*1000UL*9.25;
uint32_t  m9_30 =  60UL*1000UL*9.5;
uint32_t  m9_40 =  60UL*1000UL*9.66;
uint32_t  m9_50 =  60UL*1000UL*9.83;
uint32_t  m9_55 =  60UL*1000UL*9.916;
uint32_t  m10 = 60UL*1000UL*10UL;
uint32_t  m13 = 60UL*1000UL*13UL;
uint32_t  m15 = 60UL*1000UL*15UL;
uint32_t  m18 = 60UL*1000UL*18UL;
uint32_t  m19 = 60UL*1000UL*19UL;
uint32_t  m19_30 = 60UL*1000UL*19.5;
uint32_t  m20 = 60UL*1000UL*20UL;
uint32_t  m25 = 60UL*1000UL*25UL;
uint32_t  m28 = 60UL*1000UL*28UL;
uint32_t  m29 = 60UL*1000UL*29UL;
uint32_t  m29_30 = 60UL*1000UL*29.5;
uint32_t  m30 = 60UL*1000UL*30UL;
uint32_t  m35 = 60UL*1000UL*35UL;
uint32_t  m40 = 60UL*1000UL*40UL;
uint32_t  m45 = 60UL*1000UL*45UL;
uint32_t  m50 = 60UL*1000UL*50UL;
uint32_t  m55 = 60UL*1000UL*55UL;
uint32_t  m58 = 60UL*1000UL*58UL;
uint32_t  m59 = 60UL*1000UL*59UL;
uint32_t  m59_30 = 60UL*1000UL*59.5;
uint32_t  m60 = 60UL*1000UL*60UL;
uint32_t  m65 = 60UL*1000UL*65UL;
uint32_t  m70 = 60UL*1000UL*70UL;
uint32_t  m75 = 60UL*1000UL*75UL;
uint32_t  m80 = 60UL*1000UL*80UL;
uint32_t  m85 = 60UL*1000UL*85UL;
uint32_t  m88 = 60UL*1000UL*88UL;
uint32_t  m89 = 60UL*1000UL*89UL;
uint32_t  m89_30 = 60UL*1000UL*89.5;
uint32_t m90 = 60UL*1000UL*90UL;
uint32_t m95 = 60UL*1000UL*95UL;
uint32_t m100 = 60UL*1000UL*100UL;
uint32_t m110 = 60UL*1000UL*110UL;
uint32_t m120 = 60UL*1000UL*120UL;
uint32_t m125 = 60UL*1000UL*125UL;
uint32_t m135 = 60UL*1000UL*135UL;

//HOURS
uint32_t h2  = 1000UL*60UL*60UL*2UL;
uint32_t h3  = 1000UL*60UL*60UL*3UL;
uint32_t h4  = 1000UL*60UL*60UL*4UL;
uint32_t h6  = 1000UL*60UL*60UL*6UL;
uint32_t h7  = 1000UL*60UL*60UL*7UL;
uint32_t h7_5  = 1000UL*60UL*60UL*7.5;
uint32_t h8  = 1000UL*60UL*60UL*8UL;
uint32_t h10 = 1000UL*60UL*60UL*10UL;
uint32_t h12 = 1000UL*60UL*60UL*12UL;
uint32_t h14 = 1000UL*60UL*60UL*14UL;
uint32_t h16 = 1000UL*60UL*60UL*16UL;
uint32_t h18 = 1000UL*60UL*60UL*18UL;
uint32_t h19 = 1000UL*60UL*60UL*19UL;
uint32_t h20 = 1000UL*60UL*60UL*20UL;
uint32_t h22 = 1000UL*60UL*60UL*22UL;
uint32_t h24 = 1000UL*60UL*60UL*24UL;
uint32_t h26 = 1000UL*60UL*60UL*26UL;
uint32_t h30 = 1000UL*60UL*60UL*30UL;
uint32_t h36 = 1000UL*60UL*60UL*36UL;
uint32_t h42 = 1000UL*60UL*60UL*42UL;
uint32_t h48 = 1000UL*60UL*60UL*48UL;

// Define whether individual LED positions will be OFF (0) or ON (1). Formatted like 96-well plate
uint8_t const LEDmode[] PROGMEM ={ 
// 1   2   3   4   5   6   7   8   9  10  11  12
1,  1,  1,  1,  1,  1,  1,  1,  1,  1,  1,  1,
1,  1,  1,  1,  1,  1,  1,  1,  1,  1,  1,  1,
1,  1,  1,  1,  1,  1,  1,  1,  1,  1,  1,  1,
1,  1,  1,  1,  1,  1,  1,  1,  1,  1,  1,  1,
1,  1,  1,  1,  1,  1,  1,  1,  1,  1,  1,  1,
1,  1,  1,  1,  1,  1,  1,  1,  1,  1,  1,  1,
1,  1,  1,  1,  1,  1,  1,  1,  1,  1,  1,  1,
1,  1,  1,  1,  1,  1,  1,  1,  1,  1,  1,  1,
};       


//PHASE DEFINITIONS//
//PHASE DEFINITIONS//
//PHASE DEFINITIONS//

//Define number of phases in timecourse (including initial delay phase)
//script assumes 3 phases
const uint8_t totPhaseNum = 3;

//define phase timing using time variables from above
 const uint32_t * const phaseTimes[chanNum/3][totPhaseNum] PROGMEM = {
{&s0,&h12,&h48},  {&s0,&h8,&h48}, {&h48,&h48,&h48}, {&h48,&h48,&h48}, {&h14,&h48,&h48}, {&h14,&h48,&h48}, {&h14,&h48,&h48}, {&h14,&h48,&h48}, {&h14,&h48,&h48}, {&h14,&h48,&h48}, {&h14,&h48,&h48}, {&h14,&h48,&h48},
{&h14,&h48,&h48}, {&h14,&h48,&h48}, {&h14,&h48,&h48}, {&h14,&h48,&h48}, {&h10,&h48,&h48}, {&h10,&h48,&h48}, {&h10,&h48,&h48}, {&h10,&h48,&h48}, {&h10,&h48,&h48}, {&h10,&h48,&h48}, {&h10,&h48,&h48}, {&h10,&h48,&h48},
{&h12,&h48,&h48}, {&h12,&h48,&h48}, {&h12,&h48,&h48}, {&h12,&h48,&h48}, {&h6,&h48,&h48},  {&h6,&h48,&h48},  {&h6,&h48,&h48},  {&h6,&h48,&h48},  {&h6,&h48,&h48},  {&h6,&h48,&h48},  {&h6,&h48,&h48},  {&h6,&h48,&h48},
{&h10,&h48,&h48}, {&h10,&h48,&h48}, {&h10,&h48,&h48}, {&h10,&h48,&h48}, {&s0,&h48,&h48},  {&s0,&h48,&h48},  {&s0,&h48,&h48},  {&s0,&h48,&h48},  {&s0,&h48,&h48},  {&s0,&h48,&h48},  {&s0,&h48,&h48},  {&h48,&h48,&h48},
{&h8,&h48,&h48},  {&h8,&h48,&h48},  {&h8,&h48,&h48},  {&h8,&h48,&h48},  {&h14,&h48,&h48}, {&h14,&h48,&h48}, {&h14,&h48,&h48}, {&h14,&h48,&h48}, {&h14,&h48,&h48}, {&h14,&h48,&h48}, {&h14,&h48,&h48}, {&h14,&h48,&h48},
{&h6,&h48,&h48},  {&h6,&h48,&h48},  {&h6,&h48,&h48},  {&h6,&h48,&h48},  {&h10,&h48,&h48}, {&h10,&h48,&h48}, {&h10,&h48,&h48}, {&h10,&h48,&h48}, {&h10,&h48,&h48}, {&h10,&h48,&h48}, {&h10,&h48,&h48}, {&h10,&h48,&h48},
{&h4,&h48,&h48},  {&h4,&h48,&h48},  {&h4,&h48,&h48},  {&h4,&h48,&h48},  {&h6,&h48,&h48},  {&h6,&h48,&h48},  {&h6,&h48,&h48},  {&h6,&h48,&h48},  {&h6,&h48,&h48},  {&h6,&h48,&h48},  {&h6,&h48,&h48},  {&h6,&h48,&h48},
{&s0,&h48,&h48},  {&s0,&h48,&h48},  {&s0,&h48,&h48},  {&s0,&h48,&h48},  {&s0,&h48,&h48},  {&s0,&h48,&h48},  {&s0,&h48,&h48},  {&s0,&h48,&h48},  {&s0,&h48,&h48},  {&s0,&h48,&h48},  {&s0,&h48,&h48},  {&s0,&h48,&h48},
};

//Indicate whether using global (phase) intensities or individual(variable) intensities per each LED.
//0 to use global intensities, 1 to use individual.  
//Can do this for ON intensities (define for ON pulse, OFF pulse), OFF intensities
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

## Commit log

2018-11-14 Add files via upload
    Individual gerbers and drill file
    [optoPlate96_3col_v4H-B.Cu.gbr, optoPlate96_3col_v4H-B.Mask.gbr, optoPlate96_3col_v4H-Edge.Cuts.gbr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]
2019-01-25 Update optoPlate-96_1colorPulse.ino
    fixed bug in initial light settings in setup()
    [optoPlate-96_1colorPulse.ino]
2019-01-25 Update optoPlate-96_2colorPulse.ino
    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
    [optoPlate-96_2colorPulse.ino]
2019-01-25 Update optoPlate-96_3colorPulse.ino
    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
    [optoPlate-96_3colorPulse.ino]
2019-01-25 Update optoPlate-96_3colorPulse.ino
    fixed bug in intensity assignments for !pulsed condition in phase 1
    [optoPlate-96_3colorPulse.ino]
2019-01-25 Update optoPlate-96_2colorPulse.ino
    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
    [optoPlate-96_2colorPulse.ino]
2019-01-25 Update optoPlate-96_1colorPulse.ino
    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
    [optoPlate-96_1colorPulse.ino]
2019-03-16 Create ArduinoScripts
2019-03-16 Rename PCB gerbers/README to AssemblyFiles/PCBgerbers/README
2019-03-17 Rename file directories
    [adapter_96w_384w.stl, aluminumPlate.dxf, heatsinkPedestal_v2.stl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]
